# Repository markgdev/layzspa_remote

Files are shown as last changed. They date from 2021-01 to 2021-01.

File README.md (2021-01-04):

# LayZSpa 4 Pin Serial ESP8266 Controller
An NodeMCU/ESP8266 controller for the 4 pin version of the LayZSpa, specifically designed and tested for a 2018 LayZSpa Hawaii.

## Prototype PCB/Schematic
Located within the pcb directory are the eagle files I used to get the prototype PCB board. Hopefully the schematic below is useful to you even without the PCB.

Note that the version in here is yet to be printed as there was an error in the first version. It is however possible to set this up without a PCB, however I found it a little messy and difficult to manage when working within the pump unit.

### Schematic
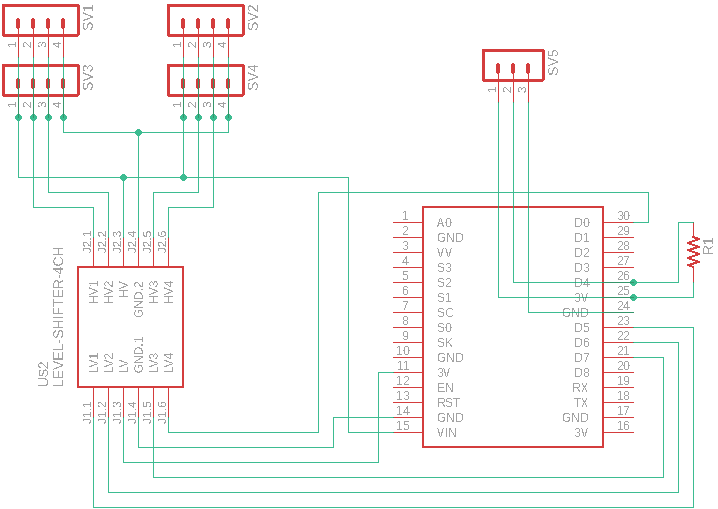
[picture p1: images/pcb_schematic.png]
Schematic


### Bill of materials
- NodeMCU V3 (Note there are other versions of NodeMCU that will not fit this printed PCB, v3 has v0.1 printed in the top right corner)
- 4 Channel bi-directional logic level shifter
- 4 pin dupoint connectors (2x)
- 4 pin JST-SM Female to terminate to dupoont
- 4 pin JST-SM Male to terminate to dupont

### Notes
- With 4 pin connectors at top of board, left side connects to DSP, right to IOC.
- Pin 1 of each connector is 5v
- Pin 4 of each connector is GND

There is a seperate 3 pin header which I plan to use in the future to connect a DS18b20 temperature sensor to give more precise temperature measurement to avoid large swings in temperature.

## Arduino Sketch
Flash your NodeMCU device with the sketch located in esp8266_sketch

Connect your PCB/NodeMCU to the pump unit with the JST-SM connectors.

Once you have flashed the device it will host a simple (needs to be improved) web interface to allow control.

http://\<ipaddress\>/

Set the desired temperature and turn on heater general to start heating/pump.

The air blower currently is only controlled through the top panel of the pump. **Note that you will loose all other control from the pump control panel!**

Unlike the standard controller the sketch will currently turn the heater back on/off as soon as the tempurature goes outside of the set temp.

There is also a json output avaiable at http://\<ipaddress\>/status, I have used a combination of this and the above address with the parameters you see when you press a button to develop a home assistant climate integration, more details below...

### ximon Hot Tub Remote
I made great use of the information on the below issue to get this working, my work is very much still in protoype and I plan to contribute back to the idea of a generic setup across the LayZSpa variants, as talked about. You may notice that the status endpoint is already the as similar as it can be. I'll work to add the other endpoints soon.

https://github.com/ximon/Hot-tub-remote/issues/4#issuecomment-753403581

## Home Assistant Installation
Clone this repo

Copy custom_components/layzspa to <homeassistant config>/custom_components/layzspa

Or Use HACS

### Configuration
```yaml
climate:
  - platform: layzspa
    ipaddr: 192.168.1.178
```

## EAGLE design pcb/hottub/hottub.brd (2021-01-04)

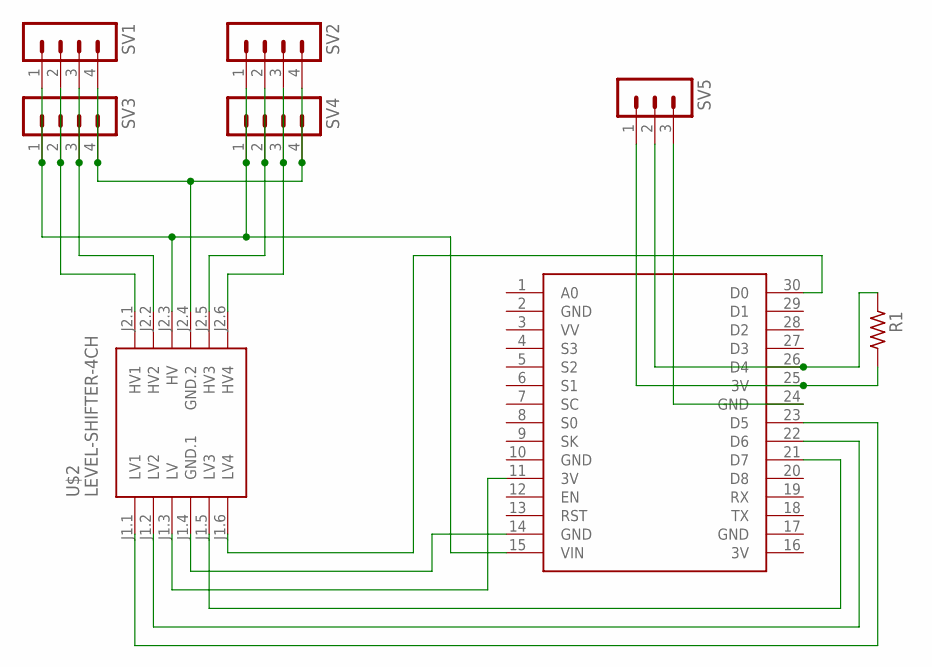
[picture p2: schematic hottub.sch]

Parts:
R1: R_1206; R1206
SV1, SV2, SV3, SV4: MA04-1
SV5: MA03-1
U$1: NODEMCU
U$2: LEVEL-SHIFTER-4CH

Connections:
3V: U$1.16 (3V)
GND: U$1.2 (GND), U$1.10 (GND), U$1.17 (GND)
unnamed: R1.2, SV5.1, U$1.25 (3V)
unnamed: SV1.2, SV3.2, U$2.J2.1 (HV1)
unnamed: SV1.3, SV3.3, U$2.J2.2 (HV2)
unnamed: SV5.3, U$1.24 (GND)
unnamed: U$1.14 (GND), U$2.J1.4 (GND.1)
unnamed: SV1.1, SV2.1, SV3.1, SV4.1, U$1.15 (VIN), U$2.J2.3 (HV)
unnamed: SV2.2, SV4.2, U$2.J2.5 (HV3)
unnamed: U$1.30 (D0), U$2.J1.6 (LV4)
unnamed: U$1.21 (D7), U$2.J1.5 (LV3)
unnamed: U$1.22 (D6), U$2.J1.2 (LV2)
unnamed: U$1.23 (D5), U$2.J1.1 (LV1)
unnamed: SV2.3, SV4.3, U$2.J2.6 (HV4)
unnamed: SV1.4, SV2.4, SV3.4, SV4.4, U$2.J2.4 (GND.2)
unnamed: R1.1, SV5.2, U$1.26 (D4)
unnamed: U$1.11 (3V), U$2.J1.3 (LV)

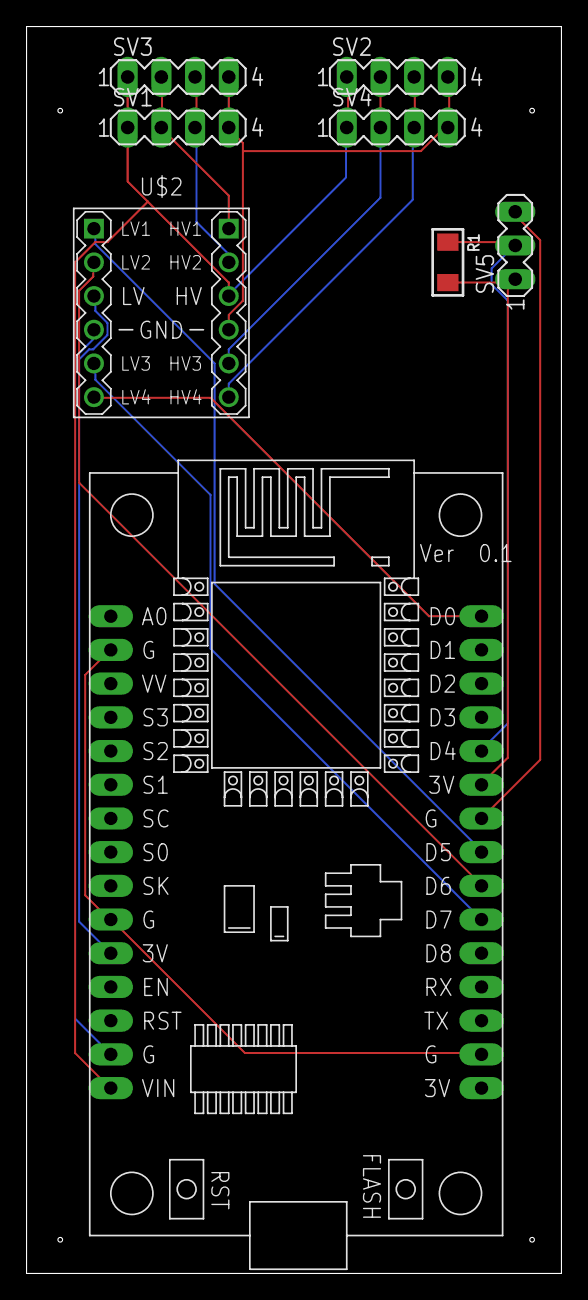
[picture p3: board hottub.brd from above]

Board: 2 copper layers, 40.3 x 94.0 mm, 8 parts (0 on the bottom side), 16 nets.

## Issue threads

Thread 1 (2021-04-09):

Some more information needed

TheCurly, 2021-04-09:
Hi Mark,

First of all, thanks for the great work! After going through the readme file, I still have a few questions:

- Would you happen to have some more information and pictures that show the connections? Pin 1 is the black cable, correct?
- Which connector goes where on the LayZspa? I would assume you plug the JST-SM Male into the pump side and the JST Female into the display side, but what are the dupoint connectors for?
- Do you have any part number for the 4 channel bi-directional logic level shifter US2?

I don't want to take too much risk with a project like this.

Best regards,
Ronny

jenswalit, 2021-04-18:
Nice work I will build this for my vegas . Pump No 54112

jenswalit, 2021-04-19:
I think SV1 is pump side and SV2 display.

markgdev, 2021-04-19:
Sorry for the delay. I will try and get some pics, I would out a multimeter on the outside pins to check the polarity.

SV1 is the display side
SV2 is the pump side, you might need to adjust the pinout in the code as I notice that the schematic goes to D0 but code is set to 5 which is D1. I haven’t got around to getting another board printed yet so haven’t hit that issue - mine is strung together with cables still.

I don’t have a part number for the level shifter but it’s similar to this: https://www.ebay.co.uk/itm/4-Channel-Bi-Directional-Logic-Level-Converter-3-3V-5V-Ardunio-ESP8266-etc-/142603531109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

Hope that helps!

jenswalit, 2021-04-19:
Many thanks for your response. Which pump do you have. Do you think I can use your codes for mine. I have the 54112.

markgdev, 2021-04-19:
I have the 54154, I would take a guess that if it’s 4 pin it uses the same protocol though. I think there is some code commented out that will print whatever is received to serial if you have issues.

jenswalit, 2021-04-19:
Thanks. Yes my pump is 4Pin. I will try this

jenswalit, 2021-04-21:
Hello and thank you very much. Can I then simply use the received data for sending or do I have to convert them?

TheCurly, 2021-04-28:
A few level converters are on order from China, I'll try to build and test once they arrive. Thanks for the extra info!

TheCurly, 2021-05-25:
Hi Mark,
My pump is the 54138, which is 4 pin as well. But I am not sure which pins to use. I have black, red yellow and green (starting from the arrow, pin1). I get 5V between pin 1 and 2 (black and red), and some pulses on pin 3 and 4 I presume since the multimeter value flashes slightly.

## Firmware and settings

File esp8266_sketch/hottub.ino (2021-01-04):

/*
  DigitalReadSerial

  Reads a digital input on pin 2, prints the result to the Serial Monitor

  This example code is in the public domain.

  http://www.arduino.cc/en/Tutorial/DigitalReadSerial
*/

// Most of the hard work on the serial comms was taken from this issue
// https://github.com/ximon/Hot-tub-remote/issues/4#issuecomment-753403581

// From DSP
// bb 03 00 00 00 03 fd
// bb = Start of DSP pkt
// 03 = 0x03
// 00 = bit 0 - general heater enable
//      bit 1 - heater 1 on, turned on 2 sec after general enable
//      bit 2 - ??
//      bit 3 - heater 2 on, turned on 30 sec after general enable
//      bit 4 - water pump on
//      bit 5 - air pump on
// 00 = 0x00
// 00 = bit 0 turns on with bit 4  but turns off after 2 sec - possible flow rate detection.
// 03 = Checksum, sum of bytes 1-4
// fd = EOF

//Heater on  01  00000001
//Heater 1   03  00000011
//Heater 2   0B  00001011
//Pump on    10  00010000
//Blower on  20  00100000

//Heater on       11  00010001 - Includes pump
//Heater 1        13  00010011 - Includes pump
//Heater 2        1B  00011011 - Includes pump
//Pump on         10  00010000
//Blower on       20  00100000
//Blower & Heater 33  00110011 - Blower, Pump, Heater 1
//Pump & Blower   30  00110000



// FROM IOC
// bc 03 15 00 00 18 fd
// bc = Start of IOC pkt
// 03 = 0x03
// 15 = Temp - 21c in this case?
// 00 = Fault or err code, 0x00 = OK
// 00 = bit 0 - 1 when IOC ready
// 18 = Checksum, sum of bytes 1-4
// fd = EOF

#include <SoftwareSerial.h>
#include <ESP8266WiFi.h>
#include <WiFiClient.h>
#include <ESP8266WebServer.h>
#include <ESP8266mDNS.h>

#ifndef STASSID
#define STASSID "examplessid"
#define STAPSK  "examplepw"
#endif

const char* ssid = STASSID;
const char* password = STAPSK;

ESP8266WebServer server(80);

// Control mode.
SoftwareSerial serialDSP(14, 12);
SoftwareSerial serialIOC(5, 13);

bool heater_general = false;
bool heater_1 = false;
bool heater_2 = false;
bool water_pump = false;
bool air = false;
byte temp = 10;
int set_temp = 38;
int err = 0;
byte ctrl = 0;

void handleRoot() {
//  String webpage = "HTTP/1.1 200 OK";
//  webpage += "Content-Type: text/html";
//  webpage += "<!DOCTYPE HTML>";
  String webpage = "<html>";
  String heater_general_str = (heater_general == 1) ? "On" : "Off";
  webpage += "Heater General: " + heater_general_str;
  webpage += " <a href=\"/cmd?heater_general=1\"\"><button>ON</button></a>";
  webpage += " <a href=\"/cmd?heater_general=0\"\"><button>OFF</button></a>";
  webpage += "<br>";
  String heater_1_str = (heater_1 == 1) ? "On" : "Off";
  webpage += "Heater 1: " + heater_1_str;
  webpage += " <a href=\"/cmd?heater_1=1\"\"><button>ON</button></a>";
  webpage += " <a href=\"/cmd?heater_1=0\"\"><button>OFF</button></a>";
  webpage += "<br>";
  String heater_2_str = (heater_2 == 1) ? "On" : "Off";
  webpage += "Heater 2: " + heater_2_str;
  webpage += " <a href=\"/cmd?heater_2=1\"\"><button>ON</button></a>";
  webpage += " <a href=\"/cmd?heater_2=0\"\"><button>OFF</button></a>";
  webpage += "<br>";
  String water_pump_str = (water_pump == 1) ? "On" : "Off";
  webpage += "Water Pump: " + water_pump_str;
  webpage += " <a href=\"/cmd?water_pump=1\"\"><button>ON</button></a>";
  webpage += " <a href=\"/cmd?water_pump=0\"\"><button>OFF</button></a>";
  webpage += "<br>";
  String air_str = (air == 1) ? "On" : "Off";
  webpage += "Bubbles!!: " + air_str;
  webpage += " <a href=\"/cmd?air=1\"\"><button>ON</button></a>";
  webpage += " <a href=\"/cmd?air=0\"\"><button>OFF</button></a><br>";
  webpage += "Temp: " + String(temp) + "&deg;C<br>";
  webpage += "Set temp: " + String(set_temp) + "&deg;C";
  webpage += " <a href=\"/cmd?set_temp=" + String(set_temp + 1) + "\"\"><button>Up</button></a>";
  webpage += " <a href=\"/cmd?set_temp=" + String(set_temp - 1) + "\"\"><button>Down</button></a><br>";
  webpage += "Error: " + String(err) + "<br>";
  webpage += "Ctrl: " + String(ctrl, HEX) + "<br>";
  webpage += "</html>";
//  Serial.println(webpage);
  server.send(200, "text/html", webpage);
}

void handleNotFound() {
  String message = "File Not Found\n\n";
  message += "URI: ";
  message += server.uri();
  message += "\nMethod: ";
  message += (server.method() == HTTP_GET) ? "GET" : "POST";
  message += "\nArguments: ";
  message += server.args();
  message += "\n";
  for (uint8_t i = 0; i < server.args(); i++) {
    message += " " + server.argName(i) + ": " + server.arg(i) + "\n";
  }
  server.send(404, "text/plain", message);
}

void handleStatus(){
//  String status = "{\"currentState\": { }}";
  String  status = "{ \"currentState\": { \"pumpState\": "+String(water_pump)+", \"temperature\": "+String(temp)+", \"heater_general\": "+String(heater_general)+", \"heater_1\": "+String(heater_1)+", \"heater_2\": "+String(heater_2)+", \"air\":"+String(air)+", \"err\":"+String(err)+" },";
          status += " \"targetState\": { \"temperature\" : "+ String(set_temp) +" } }";
  server.send(200, "application/json", status);
}

unsigned long delayStart = 0; // the time the delay started
bool delayRunning = false; // true if still waiting for delay to finish

// the setup routine runs once when you press reset:
void setup() {
  // initialize serial communication at 9600 bits per second:
  Serial.begin(9600);
  serialDSP.begin(9600);
  serialIOC.begin(9600);

  delayStart = millis();   // start delay
  delayRunning = true; // not finished yet
  
  WiFi.mode(WIFI_STA);
  WiFi.begin(ssid, password);

  // Wait for connectionse
  while (WiFi.status() != WL_CONNECTED) {
    delay(500);
    Serial.print(".");
  }
  Serial.println("");
  Serial.print("Connected to ");
  Serial.println(ssid);
  Serial.print("IP address: ");
  Serial.println(WiFi.localIP());

  if (MDNS.begin("esp8266")) {
    Serial.println("MDNS responder started");
  }

  pinMode(2, OUTPUT);
  pinMode(12, OUTPUT);
  pinMode(13, OUTPUT);
  pinMode(5, INPUT);
  pinMode(14, INPUT);
  

//  pinMode(LED_BUILTIN, OUTPUT); 
//  digitalWrite(LED_BUILTIN, LOW);

  server.on("/", handleRoot);
  server.on("/status", handleStatus);

  server.on("/cmd", []() {
    if(server.args() > 0){
      String name = server.argName(0);
      int val = server.arg(0).toInt();
      
      if(name == "heater_general"){
        heater_general = val;
        if(val == 1){
          water_pump = 1;
        }
        else{
          heater_2 = 0;
          heater_1 = 0;
        }
      }
      else if(name == "heater_1"){
        heater_1 = val;
        if(val == 1){
          water_pump = 1;
          heater_general = 1;
        }
      }
      else if(name == "heater_2"){
        if(val == 1 && air == false){
          heater_2 = val;
        }
        else{
          heater_2 = 0;
        }
        if(val == 1){
          water_pump = 1;
          heater_1 = 1;
          heater_general = 1;
        }
      }
      else if(name == "water_pump"){
        water_pump = val;
        if(val == 0){
          heater_general = 0;
          heater_2 = 0;
          heater_1 = 0;
        }
      }
      else if(name == "air"){
        air = val;
        if(val == 1){
          heater_2 = 0;
        }
        else if(val == 0 && heater_1 == 1){
          heater_2 = 1;
        }
      }
      else if(name == "set_temp"){
        Serial.println("Set temp: " + String(val));
        set_temp = val;
      }
    }
    
    handleRoot();
    send_dsp();
  });

  server.onNotFound(handleNotFound);

  server.begin();
  Serial.println("HTTP server started");
}


void send_dsp(){
//  bool heater_general = true;
//  bool heater_1 = true;
//  bool heater_2 = false;
//  bool water_pump = true;
//  bool air = false;

  if(air == 1){
    heater_2 = 0;
  }
  else if(air == 0 && heater_1 == 1){
    heater_2 = 1;
  }

  ctrl = (air << 5) + (water_pump << 4) + (heater_2 << 3) + (heater_1 << 1) + heater_general;
  byte chksum = 3 + ctrl;
  
  byte dsp_test[] = {0xbb, 0x03, ctrl, 0x00, 0x00, chksum, 0xfd};
//  Serial.println("About to send dsp pkt to IOC");
  for (int x =0; x<sizeof(dsp_test); x=x+1){
    serialIOC.write(dsp_test[x]);
  }
  
}

void send_ioc(){
//  byte temp = 30;
  byte err = 0x00;
  byte ioc_ready = 1;
  
  byte chksum = 3 + temp + err + ioc_ready;
//  bc 03 15 00 00 18 fd
//  Serial.println("Ahout to send IOC pkt to DSP");÷
  byte dsp_test[] = {0xbc, 0x03, temp, err, ioc_ready, chksum, 0xfd};
  for (int x =0; x<sizeof(dsp_test); x=x+1){
    serialDSP.write(dsp_test[x]);
  }
}


void wait_for_serial(SoftwareSerial *interface){
  int iters = 0;
  while(interface->available() == 0 && iters < 100){
        delay(10);
        iters+=1;
  }
}

void receive_dsp(){
    // Listen on DSP
  if (serialDSP.available() > 0)
  {
    
//    Serial.write("Got some data on software serial");
    int val = serialDSP.read();
//    serialDSP.flush();
//    Serial.print(val, HEX);
//    if(val == 0xFD){
//      Serial.println();
//    }
//    else {
//      Serial.print(" ");  
//    }
//    if(val == 0xBC){
//      Serial.println("Received IOC pkt on serialDSP");
//    }
    if(val == 0xBB){
      digitalWrite(2, LOW);
//      Serial.println("Got DSP pkt from serialDSP");
//      Serial.print(val, HEX);
//      Serial.print(" ");
      wait_for_serial(&serialDSP);
      byte unk = serialDSP.read();
//      Serial.print(unk, HEX);
//      Serial.print(" ");
      wait_for_serial(&serialDSP);
      byte ctrl = serialDSP.read();
//      Serial.print(ctrl, HEX);
//      Serial.print(" ");
      wait_for_serial(&serialDSP);
      byte unk1 = serialDSP.read();
//      Serial.print(unk1, HEX);
//      Serial.print(" ");
      wait_for_serial(&serialDSP);
      byte startup = serialDSP.read();
//      Serial.print(startup, HEX);
//      Serial.print(" ");
      wait_for_serial(&serialDSP);
      byte chksum = serialDSP.read();
//      Serial.print(chksum, HEX);
//      Serial.print(" ");
      wait_for_serial(&serialDSP);
      byte eof = serialDSP.read();
//      Serial.print(eof, HEX);
//      Serial.println(" ");
//      while(serialDSP.available() == 0){
//        delay(10);
//      }
      
//      heater_general = ctrl & 0x01;
//      Serial.print(val, HEX);
//      Serial.print(" ");
//      heater_1 = ctrl & 0x02;
//      Serial.print(val, HEX);
//      Serial.print(" ");
//      heater_2 = ctrl & 0x08;
//      Serial.print(val, HEX);
//      Serial.print(" ");
//      water_pump = ctrl & 0x10;
//      Serial.print(val, HEX);
//      Serial.print(" ");
      air = ctrl & 0x20;
//      Serial.print(val, HEX);
//      Serial.print(" ");
      
//      Serial.println(ctrl);
//      Serial.print("Heater General: ");
//      Serial.println(heater_general);
//      Serial.print("Heater 1: ");
//      Serial.println(heater_1);
//      Serial.print("Heater 2: ");
//      Serial.println(heater_2);
//      Serial.print("Water Pump: ");
//      Serial.println(water_pump);
//      Serial.print("Air: ");
//      Serial.println(air);
//      Serial.print("Checksum: ");
//      Serial.println(chksum);
//        send_dsp();
      digitalWrite(2, HIGH);
    }
  }
}


void receive_ioc(){
    if(serialIOC.available() > 0){
    
    int val = serialIOC.read();
//    serialIOC.flush();
//    Serial.print(val, HEX);
//    if(val == 0xFD){
//      Serial.println();
//    }
//    else {
//      Serial.print(" ");  
//    }
    if(val == 0xBC){
      digitalWrite(2, LOW);
//      Serial.println("Received IOC pkt on serialIOC");
      Serial.print(val, HEX);
      Serial.print(" ");
      wait_for_serial(&serialIOC);
      byte unk = serialIOC.read();
      Serial.print(unk, HEX);
      Serial.print(" ");
      wait_for_serial(&serialIOC);
      temp = serialIOC.read();
      Serial.print(temp, HEX);
      Serial.print(" ");
      wait_for_serial(&serialIOC);
      err = serialIOC.read();
      Serial.print(err, HEX);
      Serial.print(" ");
      wait_for_serial(&serialIOC);
      byte ioc_ready = serialIOC.read();
      Serial.print(ioc_ready, HEX);
      Serial.print(" ");
      wait_for_serial(&serialIOC);
      byte chksum = serialIOC.read();
      Serial.print(chksum, HEX);
      Serial.print(" ");
      wait_for_serial(&serialIOC);
      byte eof = serialIOC.read();
      Serial.print(eof, HEX);
      Serial.println(" ");
      if(eof != 0xFD){
        digitalWrite(2, HIGH);
        return;
      }

//      Serial.print("Temp: ");
//      Serial.print(temp);
//      Serial.println("c");
//      Serial.print("Err: ");
//      Serial.println(err);
//      Serial.print("IOC Ready: ");
//      Serial.println(ioc_ready);

//      Enable control for now.
      if(temp < set_temp && heater_general == true){
          water_pump = 1;
          heater_1 = 1;
          if(!air){
            heater_2 = 1;
          }
      }
      else if(temp > set_temp || heater_general == false){
          heater_1 = 0;
          heater_2 = 0;
      }
//      send_ioc();
      digitalWrite(2, HIGH);
    }
    
  }
}

// the loop routine runs over and over again forever:
void loop() {
  server.handleClient();
  
  receive_dsp();
  receive_ioc();
  
  if (delayRunning && ((millis() - delayStart) >= 500)) {
    delayStart = millis();
//    Serial.println("Timers run");
//    serialDSP.println("Second serial in timer");
    send_dsp();
    send_ioc();
  }
    // send data only when you receive data:
  if (Serial.available() > 0) {
    // read the incoming byte:
    int incomingByte = Serial.read();

    // say what you got:
    Serial.print("I received: ");
    Serial.println(incomingByte, HEX);
  }

//  Serial.println(0x10, HEX);
//  if (Serial.available())
//  serialDSP.write(Serial.read());
  
}

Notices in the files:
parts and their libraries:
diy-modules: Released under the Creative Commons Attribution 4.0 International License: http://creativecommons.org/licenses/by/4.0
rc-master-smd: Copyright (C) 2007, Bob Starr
